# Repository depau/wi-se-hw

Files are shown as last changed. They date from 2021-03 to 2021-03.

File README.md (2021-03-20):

# Wi-Se (Hardware)

Wi-Se is a set of ESP8266-based boards intended to be used with
[Wi-Se (firmware)](https://github.com/Depau/wi-se-sw/).

They are intended to be always connected to a device's UART header in order to
troubleshoot boot issues or crashes without having to take the board out of the
case.

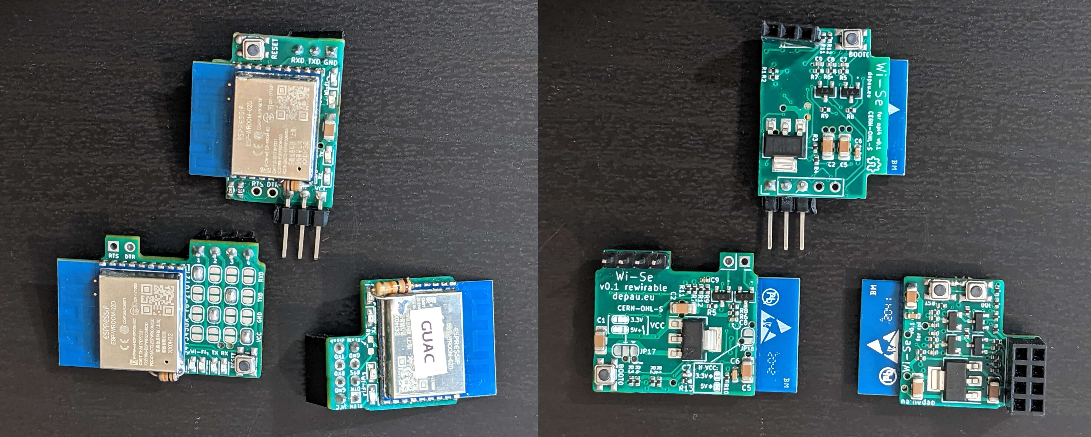
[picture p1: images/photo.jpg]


## Variants

### Rewirable

Provides solder jumpers to configure the header output. It can be powered from
5V or 3.3V.

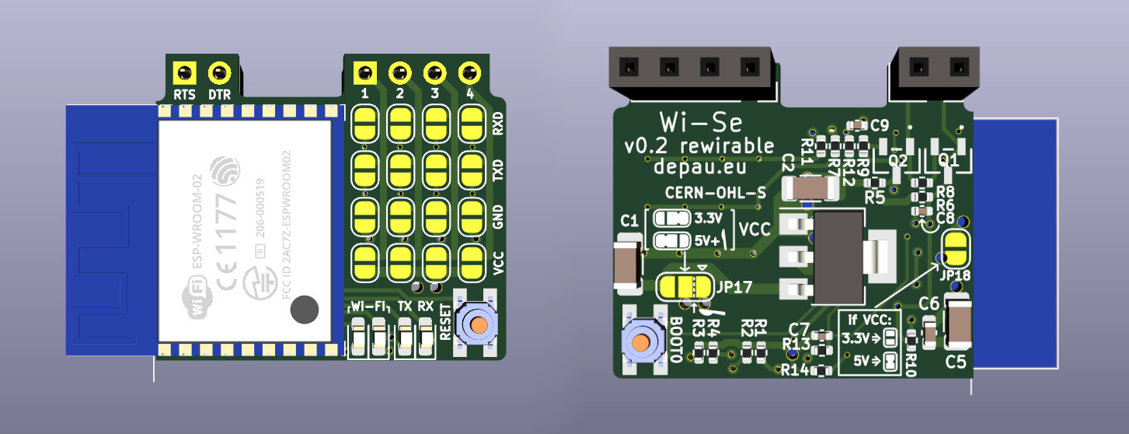
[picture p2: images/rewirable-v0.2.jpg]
Rewirable


### Raspberry Pi header

Compatible with Raspberry Pi and all boards with a compatible pinout.
Runs on 5V.

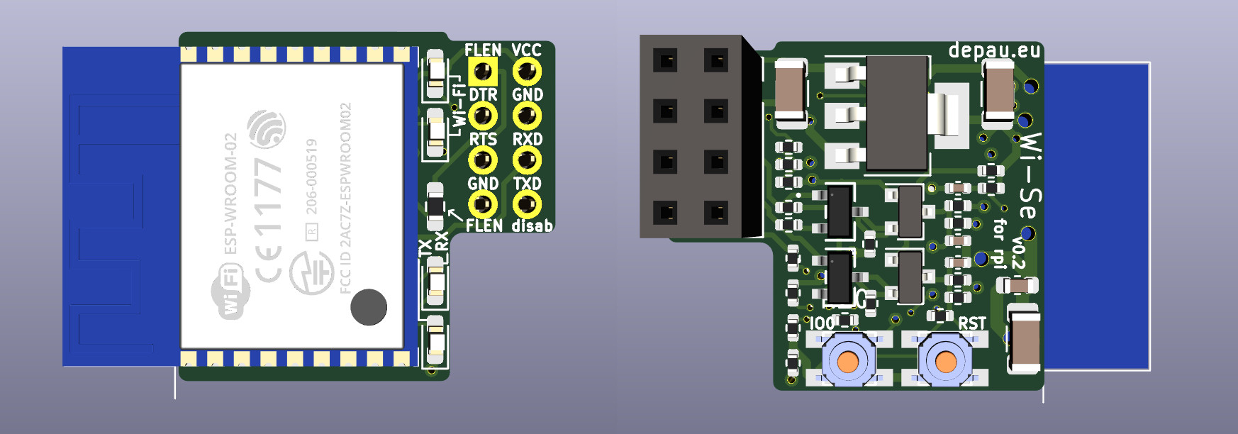
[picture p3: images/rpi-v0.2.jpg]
Raspi


### Orange Pi 4 header

Orange Pi boards have a raspi header, however the main UART is usually on 3
separate pins.

This makes connection a little more awkward, since there's no power on the UART
header and they tend to orient it differently in different boards.

In fact, this variant has been designed to fit above the PCB of the Orange Pi 4.
On an Orange Pi Zero it would work, but it would stick out from the side.

It needs a jumper wire in order to connect the 5V power line.

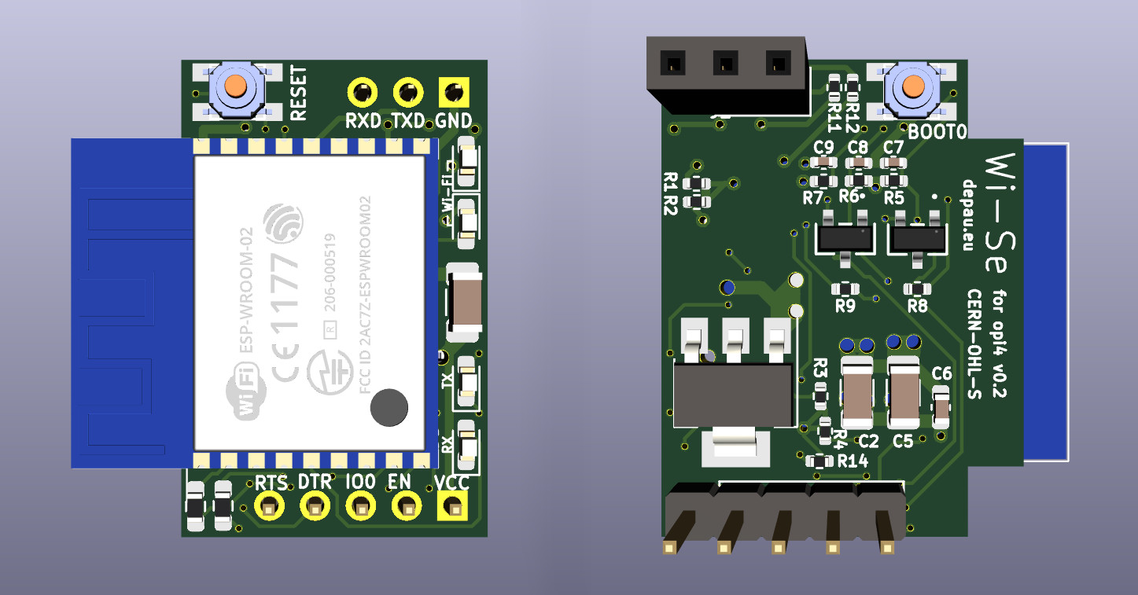
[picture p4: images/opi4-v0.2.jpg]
Opi4


**Note:** *the rendering above shows a straight male pin header for the bottom
connector. The rendering is just for demonstration purposes, a 90° male or
female header should be used instead, or a straight header but soldered on the
opposite side.*

## Revisions

### [v0.1](https://github.com/Depau/wi-se-hw/tree/v0.1)

Initial revision.

Issues:

- Missing pull-down resistor on GPIO15. Needs external resistor as can be seen
  in the pictures.
- Orange Pi 4 variant's BoM lists wrong LCSC part number for the UART resistors,
  ordering SMT assembly from JLC without correction results in UART data
  corruption. Schematics are correct.

### [v0.2](https://github.com/Depau/wi-se-hw/tree/v0.2)

Fixes the issues above.

## Specifications

The boards are stripped-down ESP8266 devkits that only perform voltage
regulation, UART communication, buttons for reset / bootloader mode, optional
headers for flashing with DTR/RTS (not tested).

The boards don't have a USB port. For initial flashing you need to connect it
to a UART adapter, then hold the GPIO0/IO0 button while pressing RESET. After
first flashing you can perform subsequent updates via Wi-Fi OTA.

## Ordering the boards

### Request assembled boards

While I do not sell the boards at the moment, I created a Google Form for people
who are interested: https://forms.gle/Le5gDNwtNsCusH8KA

This is not an order form: I will only order the boards if I get enough
requests.

Components will be ordered from China, so expect ~1 month from when I place the
order to when I will actually receive everything I need to assemble them.

### Make your own boards

The KiCad project files contain LCSC part numbers for ordering through JLCPCB.

PCB settings:

- Layers: 4
- Delivery format: single PCB
- Thickness: 1.6mm
- Color: green (SMT assembly is not available for other colors)
- Surface finish: HASL (other options are more expensive)
- Copper weight: 1 oz
- Remove order number: Specify a location (silkscreen contains JLC order number
  pattern under the ESP8266 footprint)
- Everything else set to defaults

BOM + position files compatible with JLC can be generated with the following
scripts: https://github.com/wokwi/kicad-jlcpcb-bom-plugin

If you request SMT assembly (100% recommended), please make sure the components
are aligned correctly. If they aren't you can edit the position file by hand
and correct the angle. JLC will also perform quality checks and ask your
confirmation if they notice potential issues.

The front side + tactile switches are not available on JLC's part list, so you
will have to order them separately and solder them manually.

I will provide AliExpress affiliate links once they approve my application, for
now this is the list of required components:

- ESP-WROOM-02 or ESP-WROOM-02D - 4MB flash preferred but not required
- 3x3x1.5mm SMD SPST tactile switch, 2x per board
- 0603 LEDs. Colors: 2x red, 1x amber/yellow, 1x blue.
  Current limiting resistors are tuned for these colors. If you prefer other
  colors you need to adjust the schematic.
- Pin headers, 2.54mm spacing. Type depends on your preference.

For Orange Pi 4 variant:
- 0603 1Kohm resistors, 2x per board
- 1206 10uF capacitors, 1x per board
- 1x3 pin female header, 2.54 spacing
- 1 pin 90° male header for VCC
- 1 female to female 5cm jumper cable

For Raspi variant:
- 0603 0 ohm resistor, 1x per board - **optional**
- 2x4 pin female header, 2.54mm spacing, 1x per board

For Rewirable variant:
- 1x4 pin header, 2.54mm, choose your own type based on the application

#### Cleaning the flux

I've noticed that flux tends to get under the ESP chip, glitching the board.
I would say that ultrasonic cleaning is required.

Link (with referral) for a cheap ultrasonic cleaner on Amazon.it:
https://amzn.to/38Vhwjc

## Assembly instructions

See `assembly-instructions.pdf`. The GPIO15 pull-down issue is solved in v0.2,
so unless you have a v0.1 board you don't need the external pull-down resistor.

## License

This project is licensed under the CERN Open Hardware License, Strictly
Reciprocal (CERN-OHL-S), version 2.

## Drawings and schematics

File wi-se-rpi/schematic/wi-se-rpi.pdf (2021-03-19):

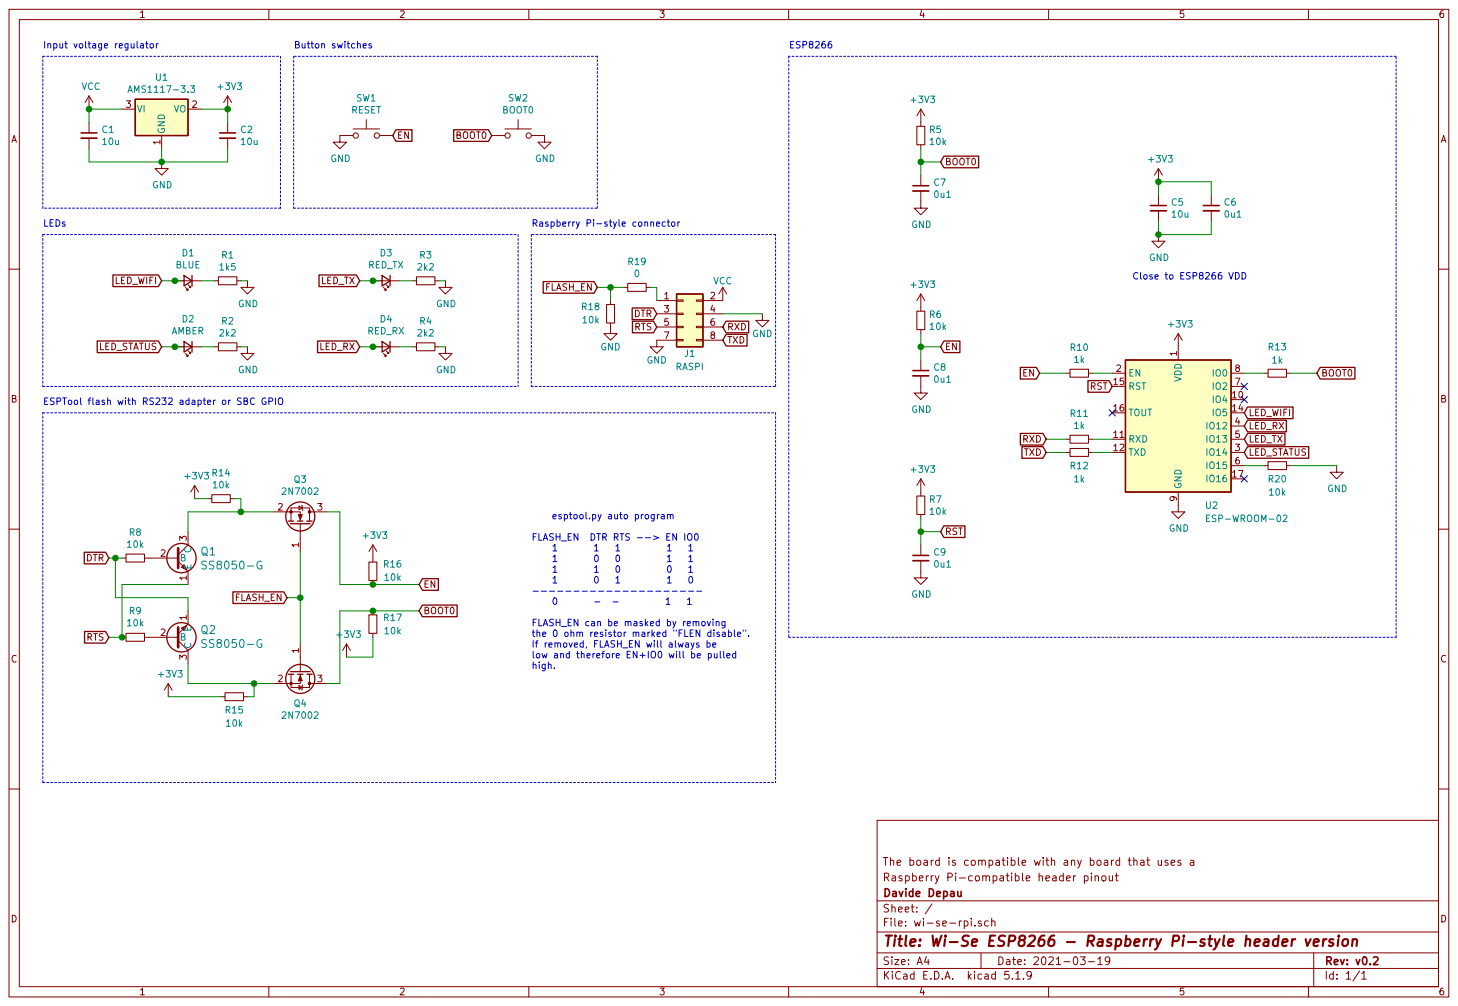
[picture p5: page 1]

LED_WIFI LED_STATUS Raspberry Pi-style connector

ESPTool flash with RS232 adapter or SBC GPIO

esptool.py auto program

the 0 ohm resistor marked "FLEN disable".
If removed, FLASH_EN will always be
low and therefore EN+IO0 will be pulled
high.

The board is compatible with any board that uses a
Raspberry Pi-compatible header pinout
File: wi-se-rpi.sch Sheet: / Davide Depau

Id: 1/1 Title: Wi-Se ESP8266 - Raspberry Pi-style header version

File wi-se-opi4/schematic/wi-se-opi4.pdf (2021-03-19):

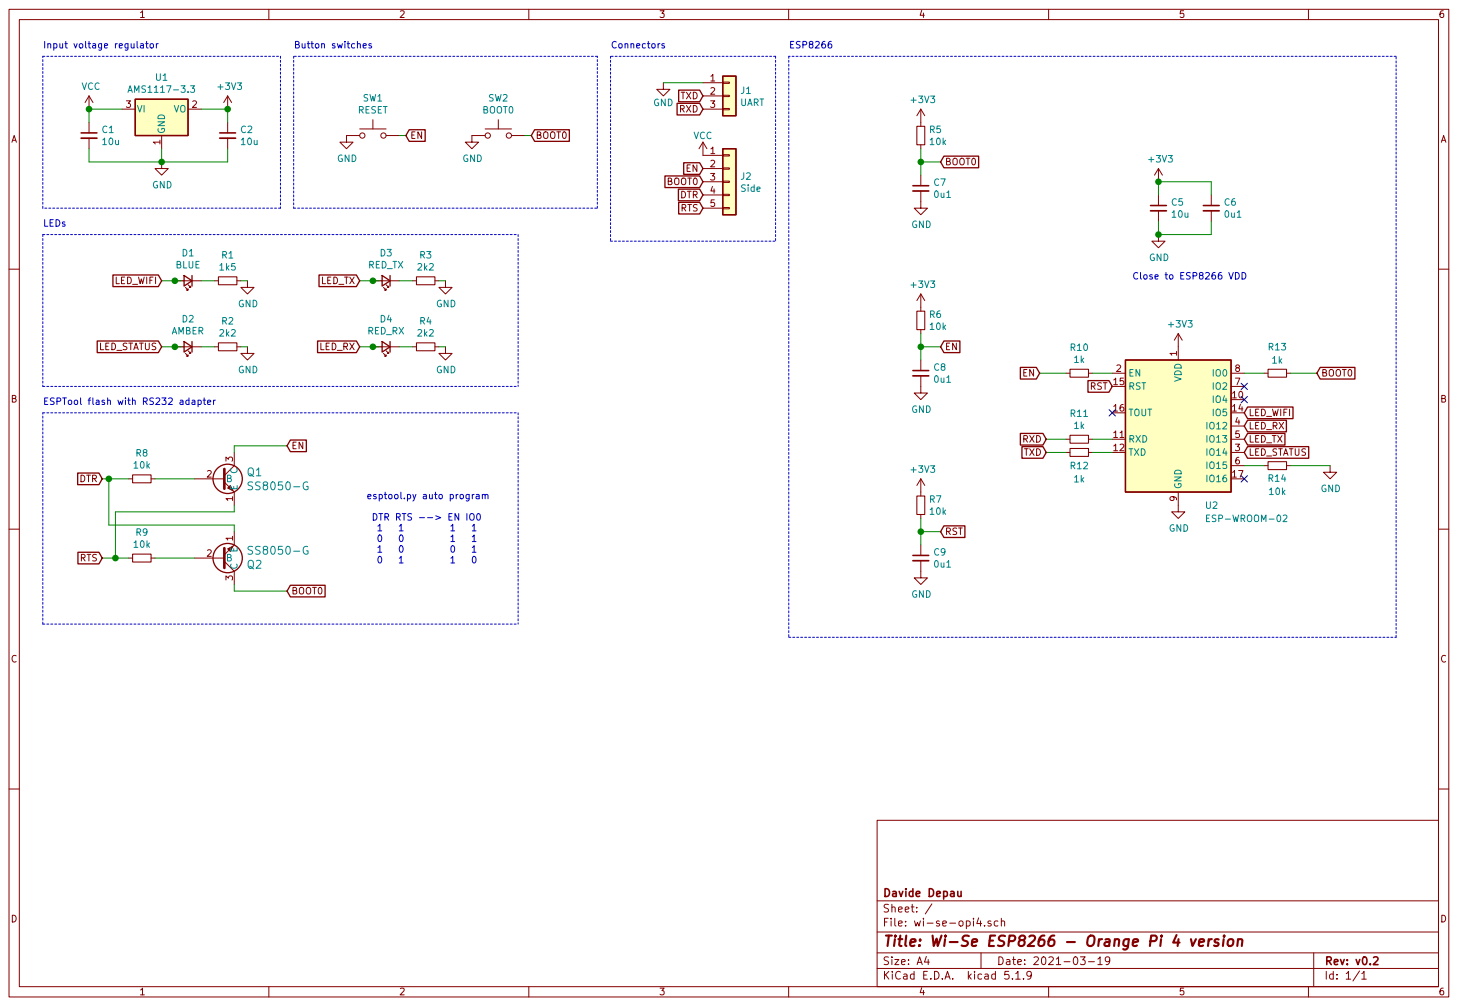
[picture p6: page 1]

esptool.py auto program

File: wi-se-opi4.sch Sheet: / Davide Depau

Id: 1/1 Title: Wi-Se ESP8266 - Orange Pi 4 version

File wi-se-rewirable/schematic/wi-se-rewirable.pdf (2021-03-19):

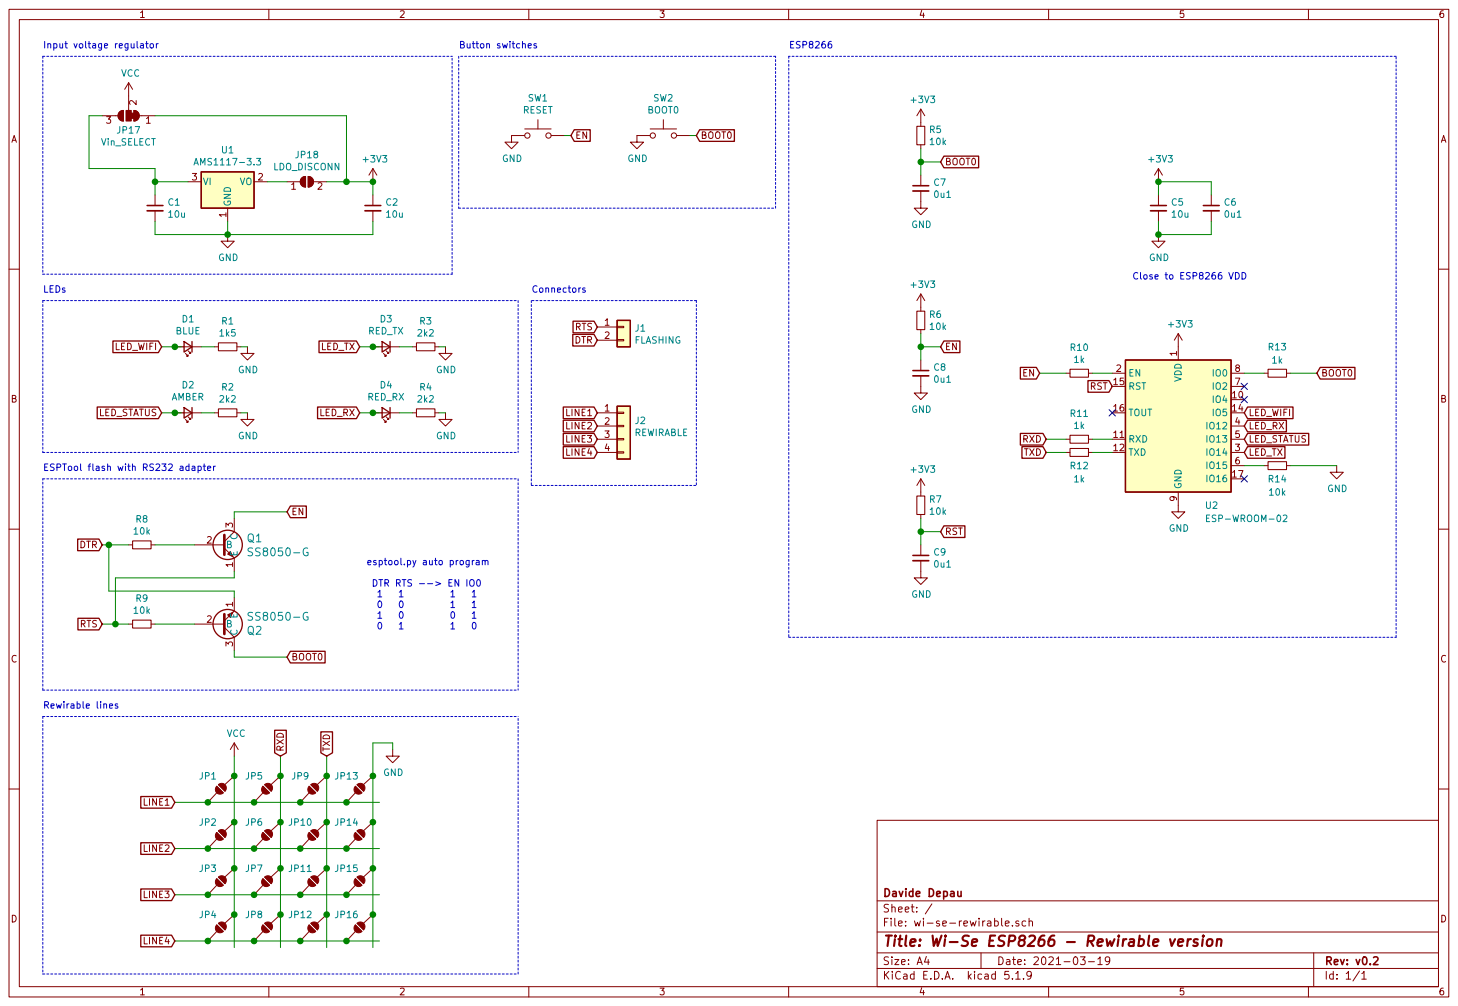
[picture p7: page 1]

Id: 1/1 Title: Wi-Se ESP8266 - Rewirable version

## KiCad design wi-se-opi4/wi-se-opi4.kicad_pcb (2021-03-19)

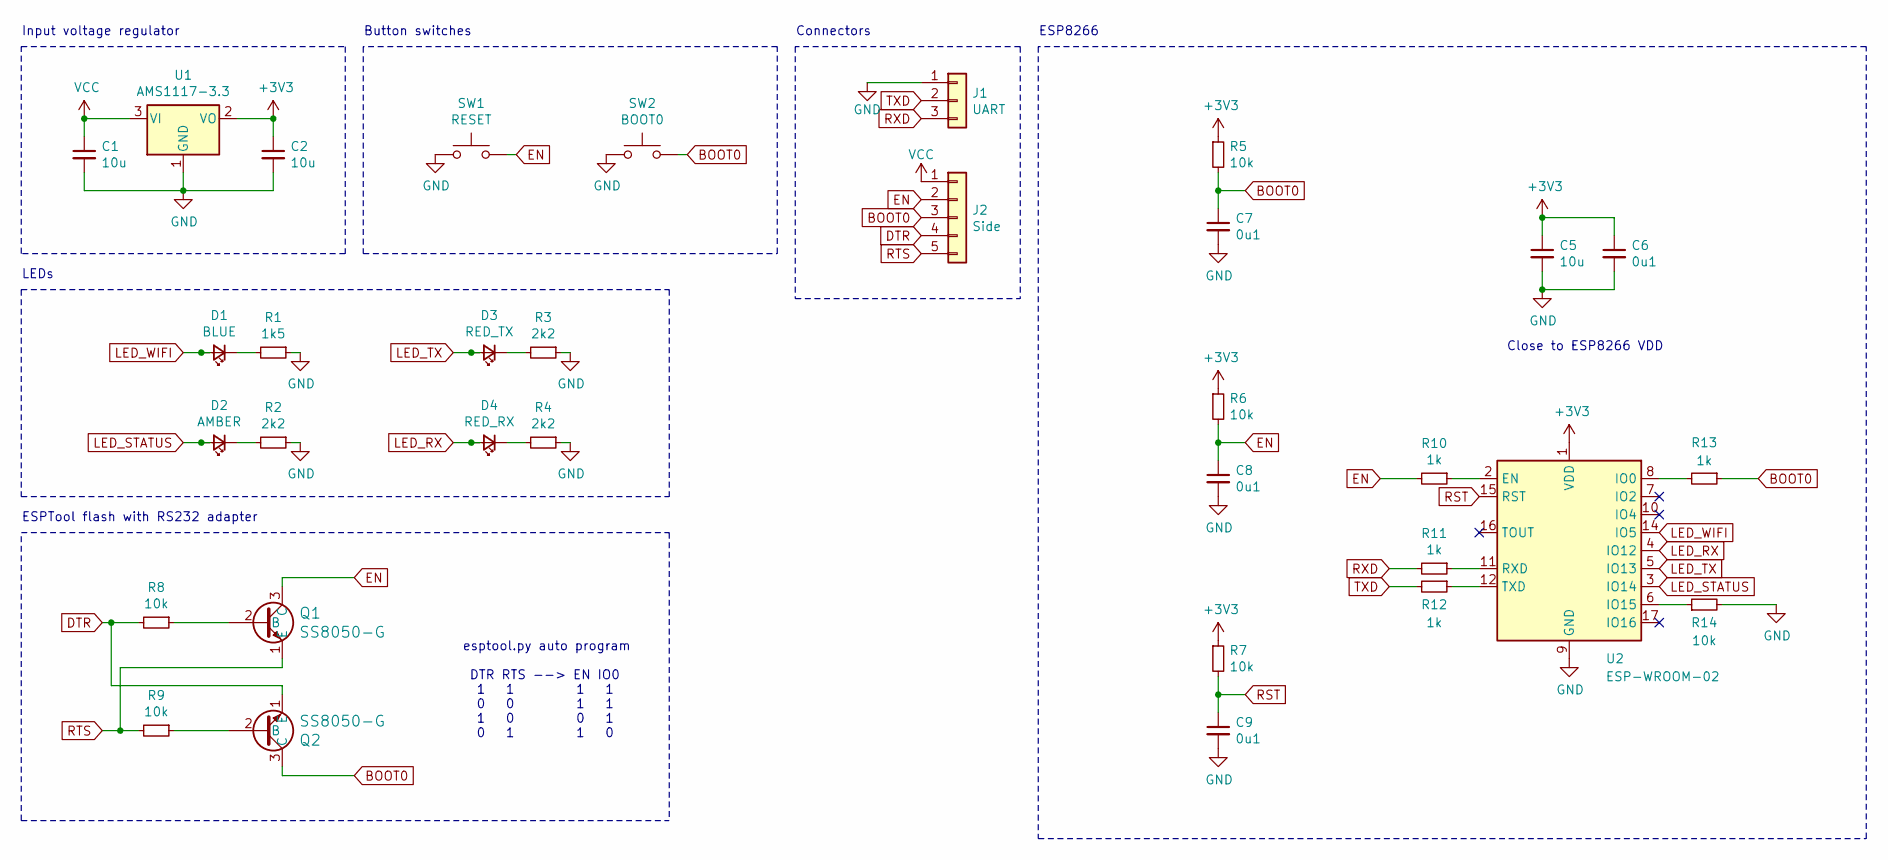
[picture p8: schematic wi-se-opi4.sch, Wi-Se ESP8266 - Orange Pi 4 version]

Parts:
C1: 10u; C_1206_3216Metric_Pad1.33x1.80mm_HandSolder; LCSC Part C13585
C2, C5: 10u; C_1206_3216Metric; LCSC Part C13585
C6: 0u1; C_0603_1608Metric; LCSC Part C14663
C7, C8, C9: 0u1; C_0402_1005Metric; LCSC Part C1546
D1: BLUE; LED_0603_1608Metric_Pad1.05x0.95mm_HandSolder
D2: AMBER; LED_0603_1608Metric_Pad1.05x0.95mm_HandSolder
D3: RED_TX; LED_0603_1608Metric_Pad1.05x0.95mm_HandSolder
D4: RED_RX; LED_0603_1608Metric_Pad1.05x0.95mm_HandSolder
J1: UART; PinSocket_1x03_P2.54mm_Vertical
J2: Side; PinHeader_1x05_P2.54mm_Vertical
Q1, Q2: SS8050-G; LCSC Part C2150
R1: 1k5; R_0402_1005Metric; LCSC Part C25867
R2, R3, R4: 2k2; R_0402_1005Metric; LCSC Part C25879
R5, R6, R7, R8, R9, R14: 10k; R_0402_1005Metric; LCSC Part C25744
R10, R13: 1k; R_0603_1608Metric_Pad0.98x0.95mm_HandSolder; LCSC Part C21190
R11, R12: 1k; R_0402_1005Metric; LCSC Part C11702
SW1: RESET; Tactile_Push_Button_SMD_3x3x1.5mm.kicad_mod
SW2: BOOT0; Tactile_Push_Button_SMD_3x3x1.5mm.kicad_mod
U1: AMS1117-3.3; SOT-223-3_TabPin2; LCSC Part C6186
U2: ESP-WROOM-02

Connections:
+3V3: C2.1, C5.1, C6.1, R5.1, R6.1, R7.1, U1.2 (VO), U2.1 (VDD)
BOOT0: C7.1, J2.3, Q2.3 (C), R5.2, R13.1, SW2.2
DTR: J2.4, Q2.1 (E), R8.2
EN: C8.1, J2.2, Q1.3 (C), R6.2, R10.2, SW1.2
GND: C1.2, C2.2, C5.2, C6.2, C7.2, C8.2, C9.2, J1.1, R1.1, R2.1, R3.1, R4.1, R14.2, SW1.1, SW2.1, U1.1 (GND), U2.9 (GND), U2.13 (GND), U2.18 (GND), U2.19 (GND)
LED_RX: D4.2 (A), U2.4 (IO12)
LED_STATUS: D2.2 (A), U2.3 (IO14)
LED_TX: D3.2 (A), U2.5 (IO13)
LED_WIFI: D1.2 (A), U2.14 (IO5)
unnamed: D1.1 (K), R1.2
unnamed: D2.1 (K), R2.2
unnamed: D3.1 (K), R3.2
unnamed: D4.1 (K), R4.2
unnamed: Q1.2 (B), R8.1
unnamed: Q2.2 (B), R9.1
unnamed: R10.1, U2.2 (EN)
unnamed: R11.1, U2.11 (RXD)
unnamed: R12.1, U2.12 (TXD)
unnamed: R13.2, U2.8 (IO0)
unnamed: R14.1, U2.6 (IO15)
RST: C9.1, R7.2, U2.15 (RST)
RTS: J2.5, Q1.1 (E), R9.2
RXD: J1.3, R11.2
TXD: J1.2, R12.2
VCC: C1.1, J2.1, U1.3 (VI)

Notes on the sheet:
Input voltage regulator
Button switches
LEDs
ESP8266
Connectors
ESPTool flash with RS232 adapter
esptool.py auto program DTR RTS --> EN IO0 1 1 1 1 0 0 1 1 1 0 0 1 0 1 1 0
Close to ESP8266 VDD

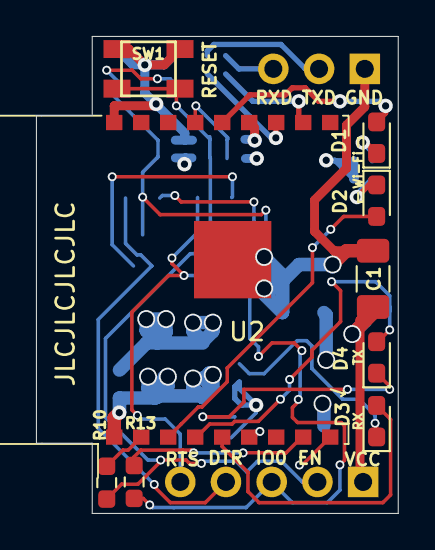
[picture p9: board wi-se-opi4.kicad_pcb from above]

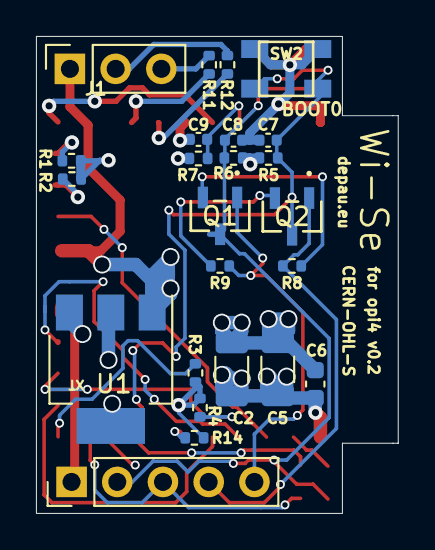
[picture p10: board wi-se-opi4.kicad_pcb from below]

Board: 4 copper layers, 20.1 x 26.5 mm, 33 parts (24 on the bottom side), 25 nets.

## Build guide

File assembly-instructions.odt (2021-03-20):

Assembly instructions

# Errata (all board types – v0.1 only)

A pull-down resistor is missing on GPIO15 to ground on v0.1 boards. Solder a 10 Kohm resistor from GPIO15 to ground or to the ESP8266 shield.

v0.2 boards have this pull-down resistor built-in so an external resistor is not required.

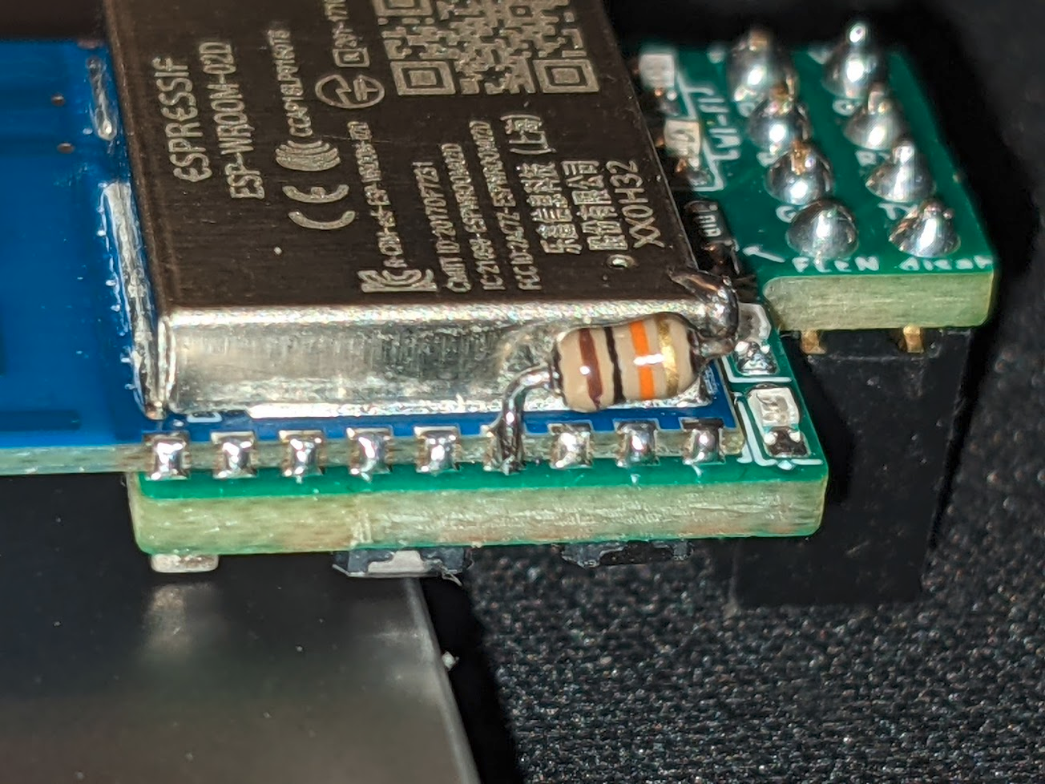
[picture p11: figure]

# Wi-Se rewirable

1. The board is pre-wired for 3.3V VCC input. If you want to use 5V, on the bottom side cut the left trace between the two right pads of the 3-way solder jumper on the left, put a solder blob on the 2-way solder jumper on the right.
2. Solder the two buttons on both sides
3. Solder the LEDs on the top side – power them externally to determine the polarity. The cathode is close to the edge of the board, the anode points inside. From right to left, looking at the board with the pin headers on top: blue, yellow, red, red
4. Solder the ESP8266.
5. (v0.1 only) Solder the 10K resistor from GPIO15 to ground, as shown in the picture in the Errata section
6. Put 4 solder blobs on the solder jumper matrix to connect the pin header pins to the preferred nets.
7. Solder the pin header. The DTR/RTS header is optional. You can also flash the board by holding down the BOOT0 button while you reset the board. If you solder it you should connect it to the same-named pins on your UART adapter, or to GPIOs on your target board.

# Wi-Se raspi header

1. Solder the two buttons on the bottom side
2. Solder the LEDs on the top side – power them externally to determine the polarity. The cathode points to the bottom of the board, when looking at it with the raspi header on the right. From the top down: blue, yellow, red, red. Note that the footprint in the middle is not for LEDs.
3. If you want to be able to flash it from the SBC without pressing buttons, solder a 0 ohm resistor in the middle footprint.
4. Solder the ESP8266.
5. (v0.1 only) Solder the 10K resistor from GPIO15 to ground, as shown in the picture in the Errata section
6. Solder a female pin header. The header MUST STICK OUT FROM THE SIDE OPPOSITE TO THE ESP8266

# Wi-Se Orange Pi 4

1. Solder the two buttons on both sides
2. Solder the LEDs on the top side – power them externally to determine the polarity. The cathode has to go on the side where the silkscreen has a [ marking. From the top down, looking at the board with the pin headers labels in the readable orientation: blue, yellow, red, red. Note that the big footprint in the middle is not for LEDs.
3. Solder the 10uF capacitor on the bigger footprint, in the middle on the right side.
4. Solder the ESP8266
5. Solder two 1Kohm resistors on the pads on the bottom left
6. (v0.1 only) Solder the 10K resistor from GPIO15 to ground, as shown in the picture in the Errata section
7. Solder a female pin header on the top side. The header MUST STICK OUT FROM THE SIDE OPPOSITE TO THE ESP8266
8. Optionally solder a 90° header on the bottom side, or a straight header sticking out from the top side. You can also flash the board by holding down the BOOT0 button while you reset the board. If you solder it you should connect it to the same-named pins on your UART adapter, or to GPIOs on your target board
9. If you don’t want to solder an entire header you still need to connect VCC to 5V. You can solder a wire directly to the VCC pin of the bottom header.

# Testing and troubleshooting

The RPI and OPI boards must be powered with 5V. The rewirable board must be powered with 3.3V unless you change the solder blob configuration as described above.

First of all, measure how much current the board draws. The RPI and OPI boards should draw around 40 mA. The rewirable board on 3.3V should draw around 30 mA. All boards should draw a very small amount of current when you hold down RESET, and the current amount should not change if you press the BOOT0/IO0 button or when you touch them.

If the current value does not make sense, there’s probably leftover conductive flux on the board. Clean it thoroughly. A ultrasonic cleaner may be required.

Once the board is clean, connect it to a UART adapter and run a terminal client program with UART settings: 74880n1.
The board should report “boot mode:(3,6)” when the reset button is pressed (embedded flash boot mode), “boot mode:(1,6)” when the BOOT0/IO0 button is held down while the reset button is pressed (esptool bootloader mode).

The second value of “boot mode” can be anything but if it isn’t 6 there may be other issues.

Meaning of the first value:

Value of “m” | GPIO15 | GPIO0 | GPIO2 | Mode | Notes
0 | 0 | 0 | 0 | Invalid
1 | 0 | 0 | 1 | UART | Esptool mode
2 | 0 | 1 | 0 | Invalid
3 | 0 | 1 | 1 | Flash | Normal boot mode
4 | 1 | 0 | 0 | SDIO
5 | 1 | 0 | 1 | SDIO
6 | 1 | 1 | 0 | SDIO
7 | 1 | 1 | 1 | SDIO

When the first boot mode number is ≥ 4, the GPIO15 pull down is not working and the board is booting in SDIO Wi-Fi adapter mode. Reflow the pull-down resistor.

Reset causes:

0 | Unidentified
1 | Power reboot or normal boot
2 | External reset using reset pin or wake up from deep sleep
3 | Software reset
4 | Hardware watchdog (WDT) reset

You should normally see rst reason 2. If you see other reset reasons, there might be issues with the board.

Once the board is booting correctly when the strapping buttons are or are not pressed, you can proceed to flashing the board.

See firmware-specific instructions in the firmware GitHub page: https://github.com/Depau/wi-se-sw

To flash the board, connect it to a USB UART adapter and power it. Make sure you use a 3.3V UART adapter. Use a terminal client program to ensure the UART lines aren’t swapped: after pressing reset you should receive a boot message from the bootrom at 74880n1.

Hold down the GPIO0/IO0 button; while still holding press RESET once, then release the GPIO0 button. While in bootloader mode, some LEDs will be dimly lit. This will also happen when the ESP8266 SoM is brand-new and the SPI flash doesn’t contain any program. In this case, ensure the the boot mode reports “boot mode:(1,#)”.
Once this is done you can run the Wi-Se builder script – ensure it is set to “serial” flashing and that the serial port is correct.

After flashing, press RESET once to reboot into the new firmware.

After flashing the boards, the blue LED will blink smoothly and the yellow LED will stay as long as the board is not connected to a network or as long as the soft access-point isn’t ready. After connection, or after the access-point is up and running, the blue LED will stay on and the yellow LED will turn off.

During normal operation, the RX and TX LEDs will blink when data is received from/transmitted to UART. The yellow LED will blink when software flow control was triggered.

The RX/TX LEDs will not blink if data is received while no client is connected. When no client is connected the firmware will ignore all data coming from the UART.

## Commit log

2021-01-14 Rename files
    [wi-se-opi4.kicad_pcb, wi-se-opi4.sch]
2021-01-16 Add RasPi header version
    [wi-se-rpi.kicad_pcb, wi-se-rpi.sch]
2021-01-17 Make RPI version as small as it can be
    [wi-se-rpi.kicad_pcb, wi-se-rpi.sch]
2021-01-18 Add Boardview generator
2021-01-18 Final version of rpi variant (last famous words)
    [wi-se-rpi-B_Cu.gbr, wi-se-rpi-B_Mask.gbr, wi-se-rpi-B_Paste.gbr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]
2021-01-18 Ground switch shields
    [wi-se-rpi-B_Cu.gbr, wi-se-rpi-B_Mask.gbr, wi-se-rpi-B_Paste.gbr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]
2021-01-18 Update Opi4 version
    [wi-se-opi4-B_Cu.gbr, wi-se-opi4-B_Mask.gbr, wi-se-opi4-B_Paste.gbr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]
2021-01-20 Add rewirable version
    [wi-se-rewirable-B_Cu.gbr, wi-se-rewirable-B_Mask.gbr, wi-se-rewirable-B_Paste.gbr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]
2021-01-20 Replace buttons with cheap aliexpress ones
    [wi-se-opi4-B_Cu.gbr, wi-se-opi4-B_Mask.gbr, wi-se-opi4-B_Paste.gbr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]
2021-01-20 Remove expensive switch
2021-01-23 Fix rewirable board name in schematic
    [wi-se-rewirable.sch]
2021-03-19 opi4: Fix LCSC part number for UART resistors
    [wi-se-opi4.sch]
2021-03-19 opi4: Add missing GPIO15 pull-down
    [wi-se-opi4.kicad_pcb, wi-se-opi4.sch]
2021-03-19 rpi: Add missing GPIO15 pull-down
    [wi-se-rpi.kicad_pcb, wi-se-rpi.sch]
2021-03-19 rewirable: Add missing GPIO15 pull-down
    [wi-se-rewirable.kicad_pcb, wi-se-rewirable.sch]
2021-03-19 Update version numbers on all documents
    [wi-se-opi4.kicad_pcb, wi-se-rewirable.sch]
2021-03-19 Regenerate schematics and boardview
    [wi-se-opi4.brd, wi-se-rewirable.brd, wi-se-rpi.brd]
2021-03-19 all: Add tactile switches 3D model
    [wi-se-opi4.kicad_pcb, wi-se-rewirable.kicad_pcb, wi-se-rpi.kicad_pcb]
2021-03-20 Add README and assembly instructions
2021-03-20 Update assembly instructions

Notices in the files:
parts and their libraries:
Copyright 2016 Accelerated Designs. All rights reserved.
